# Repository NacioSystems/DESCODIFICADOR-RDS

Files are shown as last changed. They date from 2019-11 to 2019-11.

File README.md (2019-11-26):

# DESCODIFICADOR RDS

## de NacioSystems:

Versión 1.0
Fecha: enero 2018

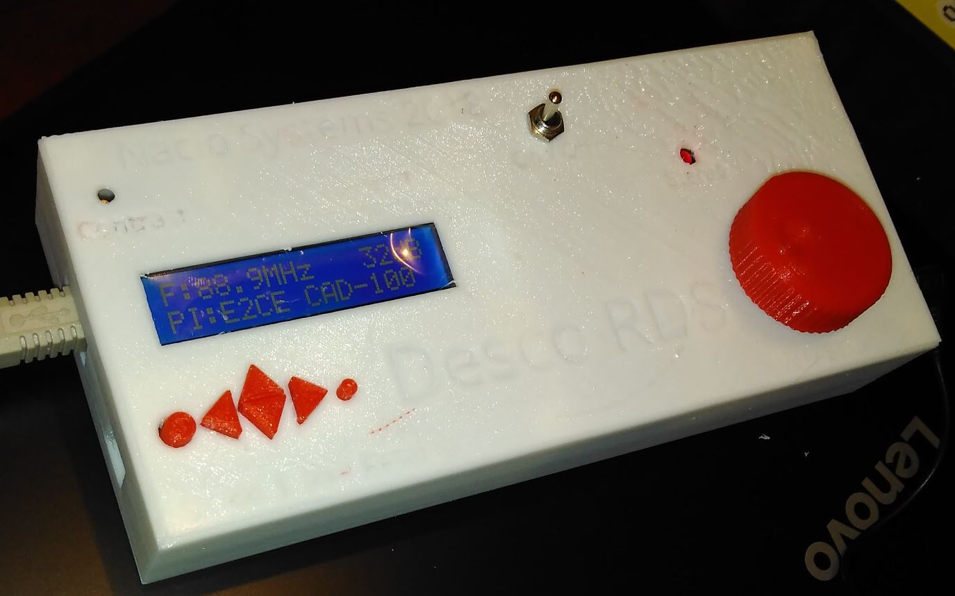
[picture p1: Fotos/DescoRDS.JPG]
DESCO RDS Desco RDS


### Indroducción:

Se trata de una radio FM con funciones básicas RDS. A través de un Arduino UNO se controla el receptor de FM con RDS Si-4703. El conjunto se complementa con una bononera y display de la placa LCD KeyPad, además de un encoder rotativo. El Arduino UNO funciona con lógica a 5V, mientras que el Si-4703 funciona a 3.3V, por ello incluye una placa adaptadora de niveles. Todo está montado sobre una caja impresa en 3D, incluyendo cuatro pilas AA de 1,5V. Es necesario disponer de unos auriculares con jack de 3,5, para las funciones de antena y poder escuchar los contenidos estereofónicos.

Tambien funciona sin baterías, conectando el puerto USB a una fuente de alimentación.

A través de la botonera se pude pasar de una frecuencia a otra, mediante escaneo a la siguiente frecuencia que se puede recibir con un nivel mínimo o por pasos de 100KHz. En el display nos indicará la frecuelncia de recepción y en caso de disponer de servicios RDS veremos también el código hexadecimal PI de la emisora y su nombre PS. También se indica el nivel de recepción de la señal radio en bornas del conector de antena/auriculares, en dBuV. Dependiendo del modo, el encoder rotativo servirá par subir bajar el volumen, que es la función principal, pero puede funcionar para subir y bajar frecuencias. Cuando una emisora está bien sintonizada se activará el LED indicando la recepcón estereofónica. Las pulsaciones de la botonera y el encoder generan un pequeño bip en el buzzer, confirmando que la tecla se ha pulsado correctamente.

No sólo es una radio convencional, es un descodificador de señal RDS, aportando la información en diferentes pantallas y modos, seleccionables con los bonones "up" y "down". Entre otras cosas aporta la siguiente información, tanto por el dsplay LCD como a través del puerto serie. En el caso de utilizar el puerto serie, al tener menos limitaciones, se ofrece una información más compelta:

* PI código hexadecimal de identificación de programa
* PS nombre de la emisora de radio o programa musical
* TP si el programa da información de tráfico
* TA si se están dando contenidos de anuncio de tráfico
* M/S si es música o palabra lo emitido
* PTY la identificación de tipo de programa, noticias, música,...
* RTX el radiotexto que pueda estar emitiendo la emisora A/B
* N, número de frecuencias alternativas
* AF frecuencias alternativas de la emisión y nivel de recepción de cada frecuencia
* G A/B informacíon estadística sobre los paquetes y grupos emitidos en RDS
* Hora UTC, Información de la fecha y hora transmitida, en caso de emitirla.

Otra funcionalidad que contempla es la grabación en la memoria EEPROM del Arduino UNO de 10 memorias con las emisoras favoritas, memoria no volátil que se mantiene incluso si se queda sin alimentación. Por defecto incluye 10 memorias ya cargadas de frecuencias del entorno de Santiago de Compostela, pero a través del teclado permite guardar en cada posición de memoria datos de nuevas emisoras.

### Materiales electrónicos:

* [Arduino UNO R3][2]
* [LCD Keypad for Arduino UNO][3]
* [Receptor FM SI-4703][4]
* [Adaptador de niveles lógicos 3,3V a 5V][5]
* [Encoder rotativo eje largo][11]
* [Porta pilas 4xAA][6]
* [Buzzer][7]
* Otro pequeño material como diodo LED, interruptor endendido, cables...

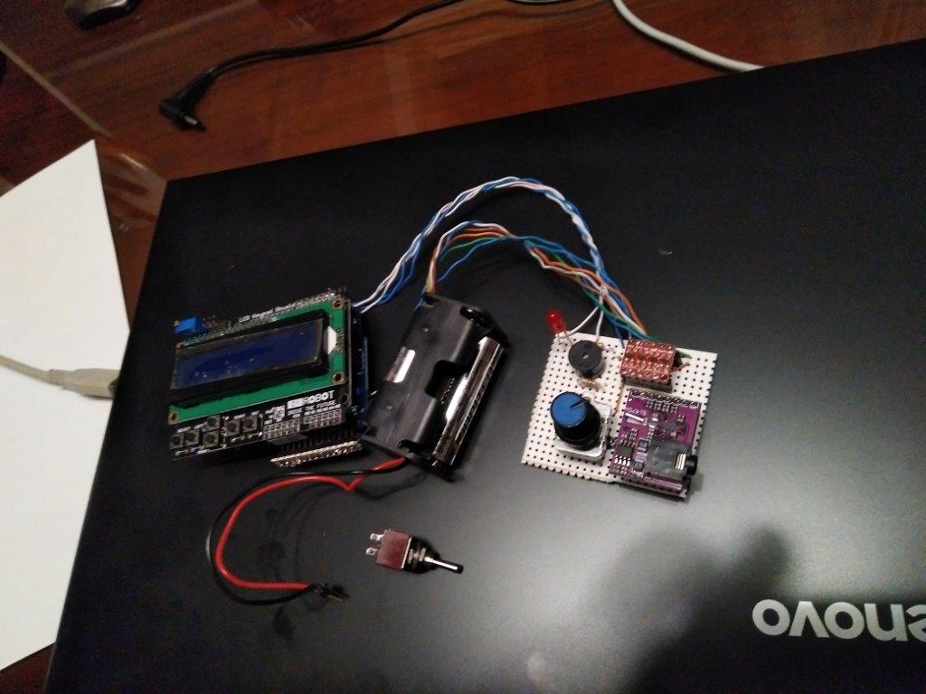
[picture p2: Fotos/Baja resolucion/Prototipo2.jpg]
Prototipado


### Piezas impresas:

La caja soporte está realizada a través de impresión en 3D, con PLA. Los modelos STL se pueden descargar del repositorio:

* [Caja principal][8]
* [Botonera][9]
* [Tapa posterior][10]

[8]: https://github.com/NacioSystems/DESCODIFICADOR-RDS/blob/master/Modelos%203D/DescoRDS.stl
[9]: https://github.com/NacioSystems/DESCODIFICADOR-RDS/blob/master/Modelos%203D/botones.stl
[10]: https://github.com/NacioSystems/DESCODIFICADOR-RDS/blob/master/Modelos%203D/tapa.stl

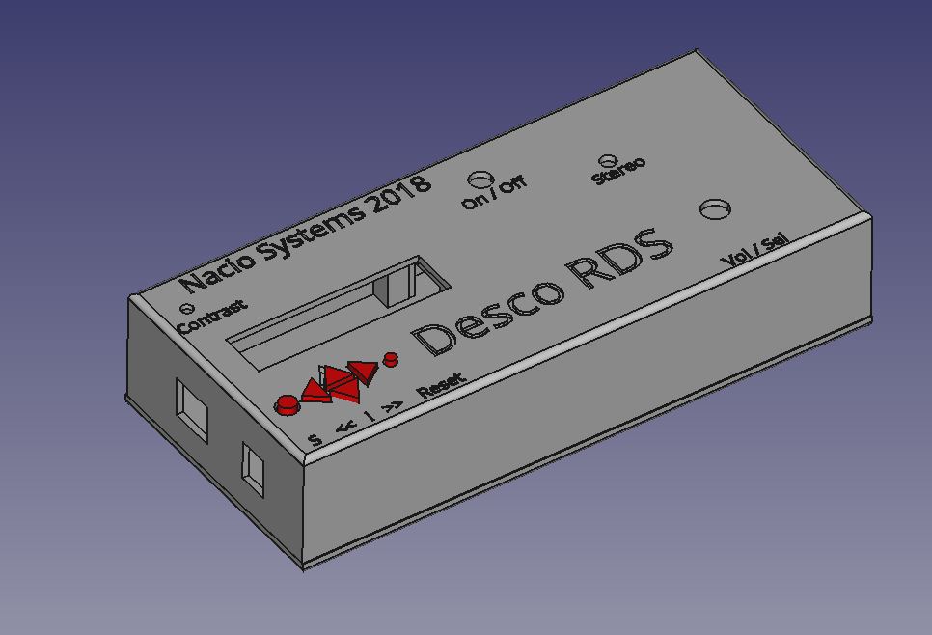
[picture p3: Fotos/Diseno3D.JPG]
Caja 3D Diseño caja 3D


### Mejoras pendientes:

Está pendiente incluir una antena telescópica fija, para no depender de los auriculares. También un pequeño amplificador con altavoz para escuchar la señal emitida sin auriculares. Implementar el cambio automático de emisora a través de las frecuencias alternativas y el código PI, cuando la calidad de recepción se reduce.

Otra funcionalidad es la cambiar el Arduino UNO por un NodeMCU ESP8266. De esta manera nos ahorramos la placa adaptadora de niveles al funcionar todo a 3,3V y  podremos hacer una gestión y control remoto de todo el dispositivo a través de TCP/IP por Wifi.

### Autor:

**Ignacio Otero**

### Agradecimientos:

Muchas gracias [**J_RPM**][1] por tus tutoriales sobre RDS.

Gracias también a [**Spark Fun Electronics**][4], de quien aprovecho las librerías Si4703.

### Licencia:

Todos estos productos están liberados mediante Creative Commons Attribution-ShareAlike 4.0 International License.

[1]: http://j-rpm.com/category/fundamentos-de-la-transmision-fm/page/3/
[2]: https://store.arduino.cc/arduino-uno-rev3
[3]: https://www.amazon.es/Aptotec-Keypad-Arduino-Mega2560-Duemilanove/dp/B01BI6UKHW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
[4]: https://learn.sparkfun.com/tutorials/si4703-fm-radio-receiver-hookup-guide/all
[5]: https://tienda.bricogeek.com/herramientas-de-prototipado/82-conversor-de-niveles-logicos-33-5v.html
[6]: https://tienda.bricogeek.com/componentes/943-base-para-baterias-4xaa-cilindrica.html
[7]: https://tienda.bricogeek.com/componentes/299-zumbador-piezo-12mm.html
[11]: https://www.amazon.es/Ociodual-CODIFICADOR-ROTATORIO-PULSADOR-Encoder/dp/B075NJSMWM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

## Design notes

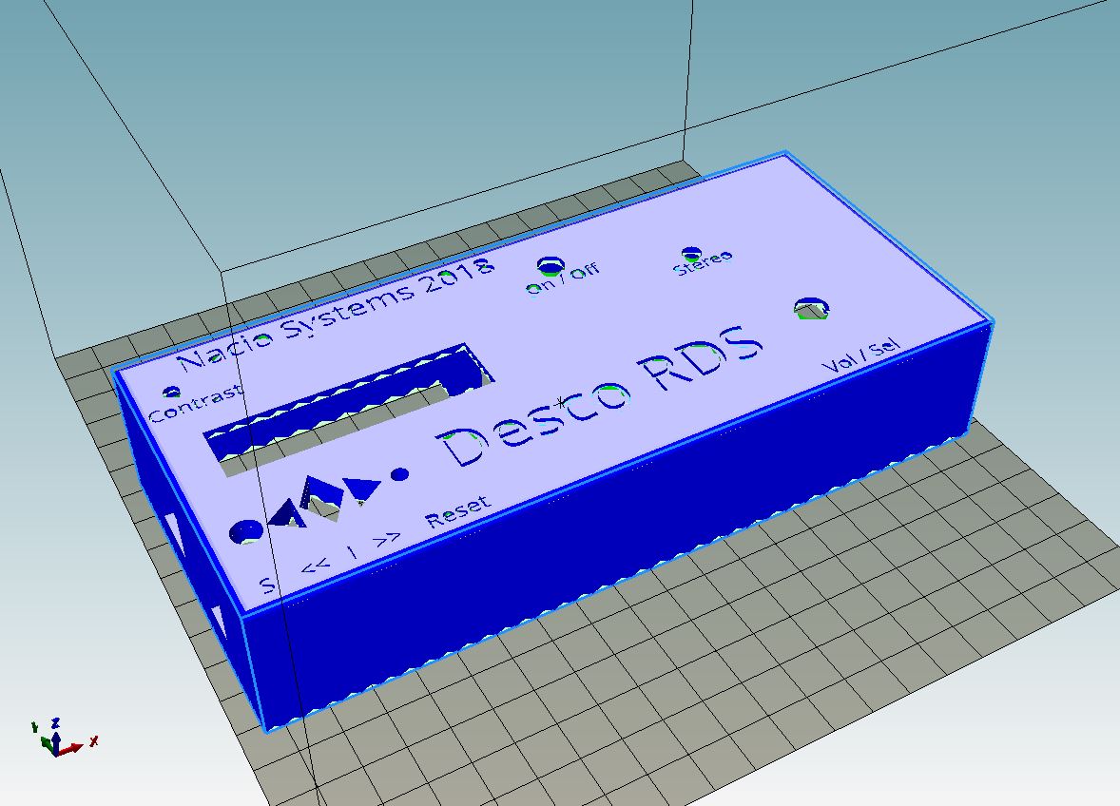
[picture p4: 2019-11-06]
Fotos/Caja3D.JPG

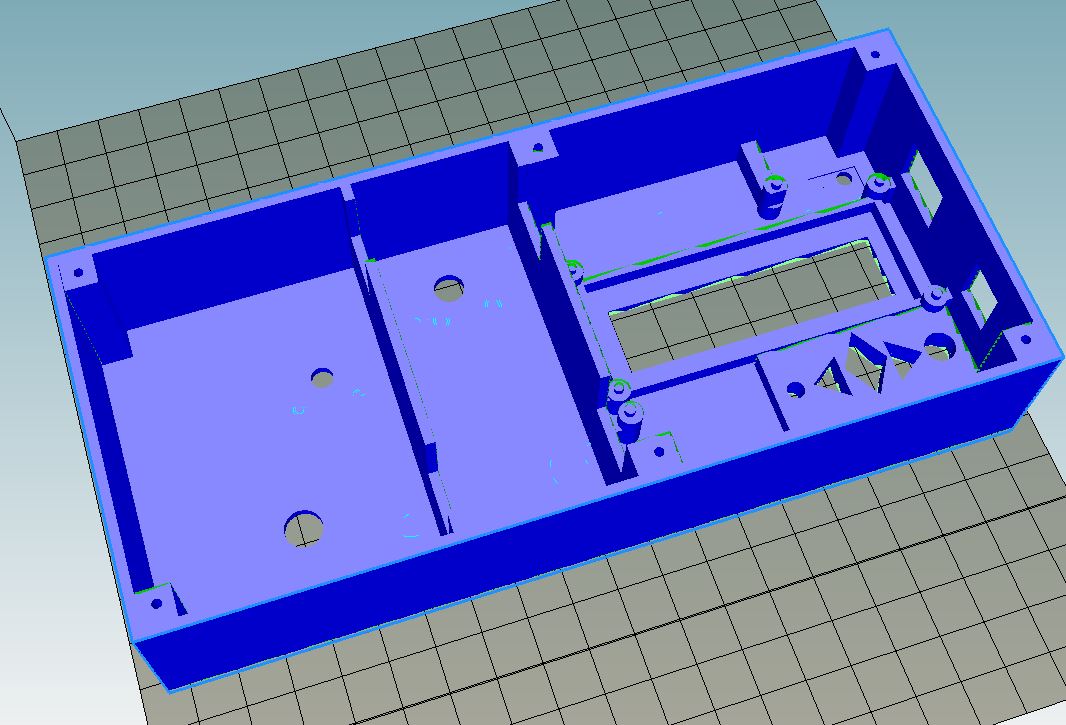
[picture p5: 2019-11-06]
Fotos/Interior.JPG

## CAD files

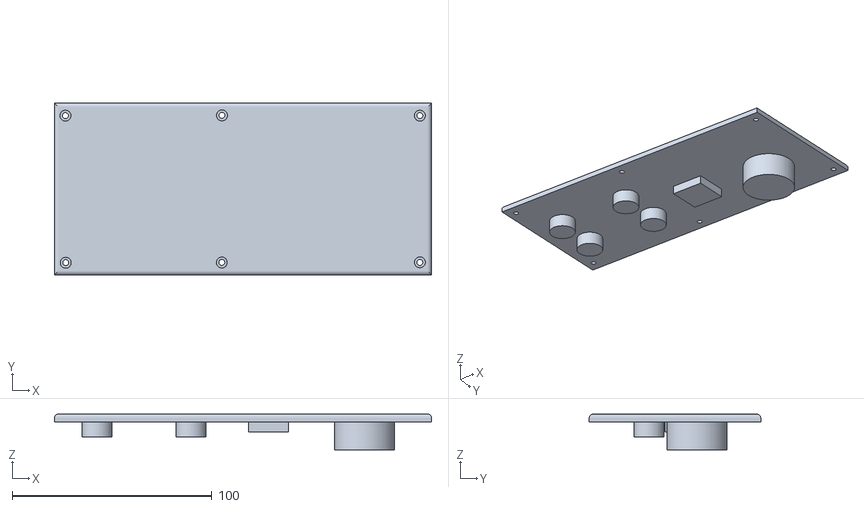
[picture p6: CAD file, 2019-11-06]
Modelos 3D/Tapa.stl
188.9 x 86.0 x 18.0

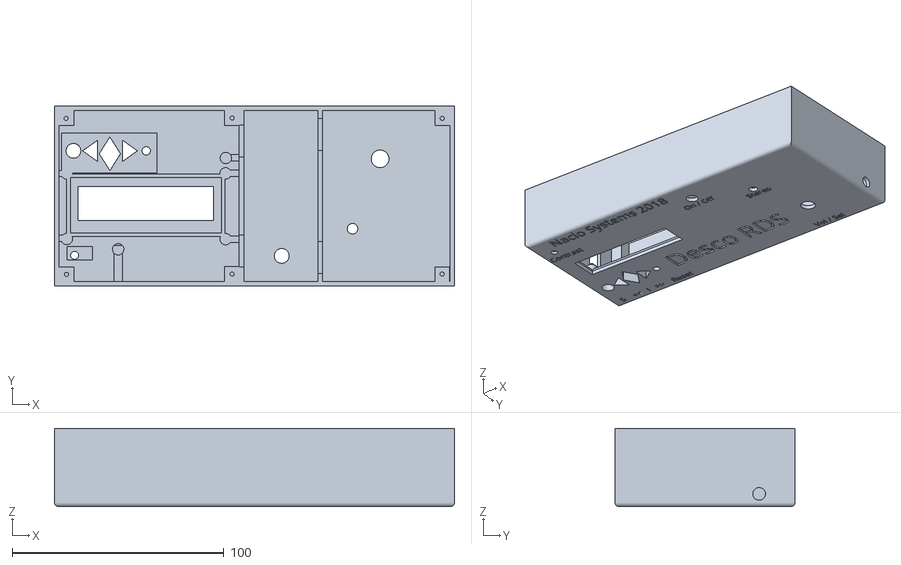
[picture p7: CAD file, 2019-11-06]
Modelos 3D/DescoRDS.stl
188.9 x 85.0 x 37.0

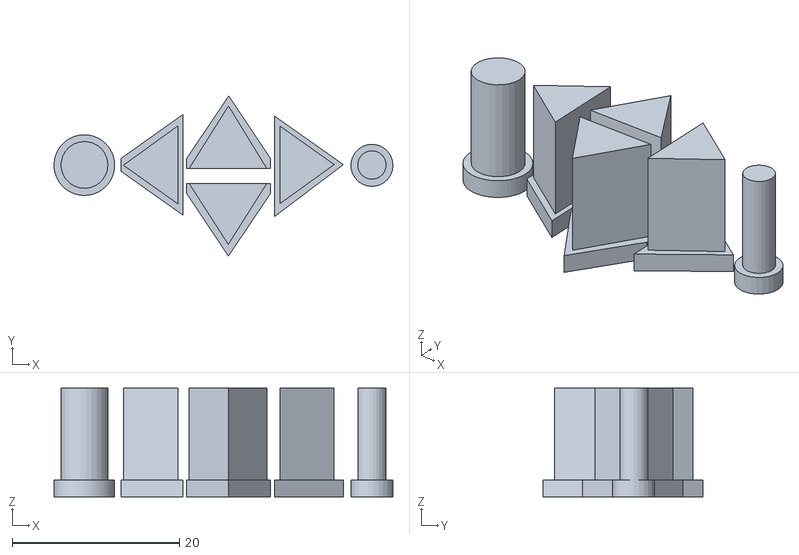
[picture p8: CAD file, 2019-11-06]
Modelos 3D/botones.stl
40.5 x 19.1 x 13.0

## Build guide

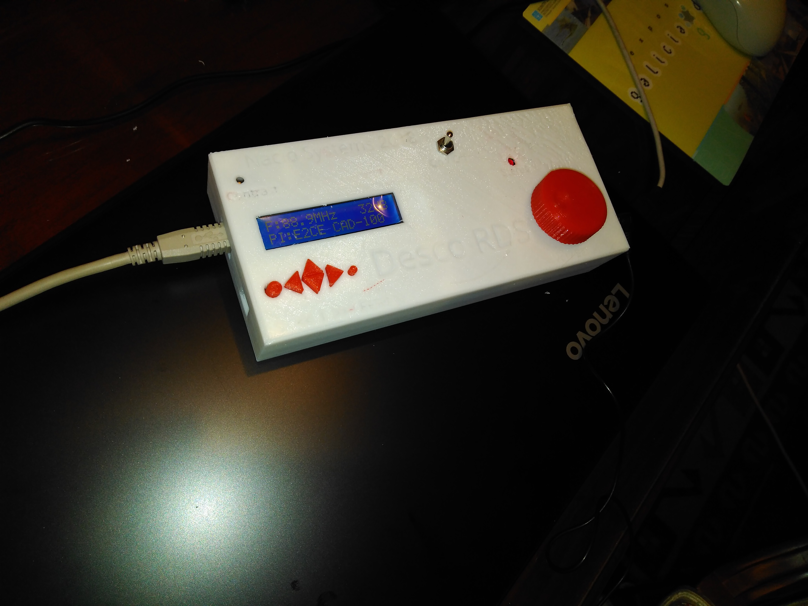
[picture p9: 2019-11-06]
Fotos/Montaje.jpg

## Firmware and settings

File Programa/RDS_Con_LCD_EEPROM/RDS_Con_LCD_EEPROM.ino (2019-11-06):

/*
  Modificado por Ignacio Otero para obtener datos de RDS en enero 2018
  Referencias:
  - Spark Fun
  1-6-2011
  Spark Fun Electronics 2011
  Nathan Seidle

  - CENELEC 50067 / 1998

  - J_RPM WWW.YOUTUBE.COM/
  https://www.youtube.com/watch?v=Hiti3FGuOgI&list=PLu7bTAqPV8_y0-5Ok_vPMW8Hp26_XmIxC

  This code is public domain but you buy me a beer if you use this and we meet someday (Beerware license).

  To use this code, connect the following 5 wires:
  Arduino : Si470x board
  3.3V : VCC
  GND : GND
  A5 : SCLK
  A4 : SDIO
  A3 : RST
  D3  SDIO2 (Int 1)

  Look for serial output at 57600bps.

  The Si4703 ACKs the first byte, and NACKs the 2nd byte of a read.

  1/18 - after much hacking, I suggest NEVER write to a register without first reading the contents of a chip.
  ie, don't updateRegisters without first readRegisters.

  If anyone manages to get this datasheet downloaded
  http://wenku.baidu.com/view/d6f0e6ee5ef7ba0d4a733b61.html
  Please let us know. It seem to be the latest version of the programming guide. It had a change on page 12 (write 0x8100 to 0x07)
  that allowed me to get the chip working..


 Si4703 CUIDADO! ESTE CHIP SÓLO ADMITE NIVELES DE 3,3V
--------------------------------------------------------------------

En los puertos están disponibles, A1, A2 y D0, D1 (RX / TX)
*/

#include "Configuracion.h" // Están todas las definiciones del programa
#include <Wire.h>
#include <EEPROM.h>       // Guardamos los datos de las memorias en la EEPROM

// Definimos un objeto RADIO de la clase Si4703 con las siguentes conexiones
// Si4703(int resetPin, int sdioPin, int sclkPin, int intPin);
#include "Si4703.h"
Si4703 RADIO(resetPin, SDIO, SCLK, GPIO2);

// Definimos un objeto lcd de la clse LiquidCrystal   
#include <LiquidCrystal.h>
LiquidCrystal lcd(RS, ENABLE, DB4, DB5, DB6, DB7);


// VARIABLES GENERALES
             int ModoPantalla = 1;  // Empieza el LCD con la pantalla principal
             boolean ModoConfiguracion = false;


             int Tecla = btnNONE; // Por defecto la tecla leida será 5

             char printBuffer[50]; // Utilizamos este string para formateo de impresión
             uint16_t si4703_registers[16]; //Son los 16 registros de Si4703, cada uno de 16 bist


             // Variables RDS en Grupo 0A
             uint16_t Pi = 0x00; // PI Program Station Identification Ah + Al
             uint8_t GP = 0; // Program Group Bh, b5-b8
             char Bcero = 'A'; // Es el tipo de grupo A=0 o B=1 en Bh bit 4
             boolean TP = 0, TA = 0; // Traffic Program b3 Bh y Traffic Anouncement b5 Bl
             uint8_t PTY = 0; // Program Type Bh + Bl b6-b8, 5 bits
             //String TextoPTY = "Indefinido"; // Esto lo hago para poner el texto de programa
             boolean MS = 0; // Modo de programa 0 Speech 1 Music
             String MSTexto = "_____"; // En vez de poner el bit pongo Speech o Music
             boolean DI = 0, PTYdinamico = 0, Comprimido = 0, Artificial = 0, Estereo = 0;
             uint8_t Control = 0; // 2 bits C1 y C0 para decodificar PS
             char PS[9] = "________\0"; // Program Station Name Ch + Cl en Grupo 0A
             uint8_t AF[26]; // Tabla de frecuencias alternativas en Grupo 0A
             uint8_t NAF = 0; // Número de AF en Grupo 0A
             int ContadorAF = 0; // Vamos contando AF hasta el máximo de 26 o código 0xCD

             // Variables del Grupo 2A 2B radio texto
             String RTA = "_______________________________________________________________"; // Radio texto en grupo A, 4 bytes en C y D
             String RTB = "_______________________________________________________________"; //Radio texto en grupo B, 2 bytes en D
             boolean TextAB = 0; // bit 5 de Bl para G2, para leer RT A o B
             boolean BanderaAB = 0; // Para comprobar que TextAB cambia

             // Varialbes del grupo 4A horas y minutos
             uint8_t Horas=0;
             uint8_t Minutos=0;
             uint8_t Segundos=0;
             int UTC=0;            // UTC puede ser negativo
             unsigned long MJD=0;  // MJD ocupa 17 bits, hacen falta 4 bytes
             uint8_t Dia=0;
             uint8_t Mes=0;
             uint16_t Ano=0;       // Es más de 256
             uint8_t ContDia=0;
             
             const char* TextoPTY[32] = {"None",    // 0
                                         "News",    // 1
                                         "Affairs", // 2
                                         "Info",    // 3
                                         "Sport",   // 4
                                         "Educate", // 5
                                         "Drama",   // 6
                                         "Culture", // 7
                                         "Science", // 8
                                         "Varied",  // 9
                                         "Pop M",   //10
                                         "Rock M",  //11
                                         "Easy M",  //12
                                         "Light M", //13
                                         "Classics",//14
                                         "Other M", //15
                                         "Weather", //16
                                         "Finance", //17
                                         "Children",//18
                                         "Social",  //19
                                         "Religion",//20
                                         "Phone In",//21
                                         "Travel",  //22
                                         "Leisure", //23
                                         "Jazz",    //24
                                         "Country", //25
                                         "Nation M",//26
                                         "Oldies",  //27
                                         "Folk M",  //28
                                         "Document",//29
                                         "TEST",    //30
                                         "Alamr!"   //31
                                         };
                                          
             const char* DiaSem[7]={"lunes","martes","miercoles","jueves","viernes","sabado","domingo"}; // Para que funcione tiene que ser puntero de Char

             // Grupos
             uint16_t GrupoA[16]; // Es para contar los grupos recibidos
             uint16_t GrupoB[16]; 
             uint16_t ContadorGrupo = 0; // Cuenta el total de grupos recibidos

             // Valores leidos de Si4703 en variables
             byte rssi = 0; // Nivel recibido en registro STATUSRSSI[0:7]
             // Son incrementos de 1dBuV, máximo 75 dBuV

             // Control del volumen extendido
             boolean VolumenExtendido = 0; // Por defecto=0;
             uint8_t Volumen = 10; // El máximo sería 31, 5 bits
             boolean Mute=true;
             // Si es menor que 17 sería Extendido
             uint8_t VolumenAnterior=Volumen;

             // Brillo pantalla lcd
             uint8_t Brillo=50;
             
             // Variables utilizadas en las interrupciones 
             volatile int Contador = 875; // La utilizaremos para la sintonia 875 - 1080
                                          // el volumen 0 - 31
                                          // Brillo del display 0 - 255
             volatile boolean RDSOK = false; // Nos dirá por interrupción si hay datos RDS
             boolean ESTEREOK = true; // El Si4703 nos da información de si la señal es estero                             

             // Memorias prefijadas 
             struct ObjetoMemoria {                      // Cada memoria ocuparía 9 + 2 + 2 = 13 bytes
                                    char     PS[9];      // Es el nombre de la emisora memorizada, poner null en el 9
                                    uint16_t Frecuencia; // Es la frecuencia en cientos de KHz, ejem. 875 es 87.5
                                    uint16_t Pi;         // Es la Identificación de Programa en hexadecimal
                                    };
             
             ObjetoMemoria Memorias;                     // En un array de 10 memorias metemos los datos de las memorias
                                                         // Ocuparían 13 x 10 = 130 bytes
                                                         // Los parámetros se llamarían por Memorias[i].Frecuencia...
                                                         
             int8_t ContadorMemorias = 5; // Cadena 100
             unsigned long tiempo = 0;
             unsigned long TSeg=0;
             boolean BuzzerON=true;

 
void setup() {
  // Inicializamos Interrupciones y Encoders
  pinMode(encoderA, INPUT_PULLUP); // Van conectados directamente
  pinMode(encoderB, INPUT_PULLUP); // a 5V, por eso pullup
  pinMode(GPIO2, INPUT_PULLUP);    // Aunque en la configuraión de GPIO ya esta a pull_up
  pinMode(resetPin, OUTPUT);       // Utilizamos A4 como digital esto ya lo hace init()
  pinMode(BuzzerPin, OUTPUT);      // La salida de D11 será la señal buzzer
  attachInterrupt(0, LeerEncoder, CHANGE); // Interrupción 0 para encoder
  attachInterrupt(1, DatosRDS, FALLING);   // Interrupcion 1 para RDS 
   
  
  // Inicializar el LCD
  lcd.begin(16, 2);
  lcd.setCursor(0, 0);
  lcd.print("Ignacio Otero");
  lcd.setCursor(0, 1);
  lcd.print("Desco RDS 2018");
  delay(2000);
  lcd.noDisplay();
  delay(2000);
  lcd.display();

  pinMode(STATUS_LED, OUTPUT);
  pinMode(BOTONES, INPUT); // Leemos el teclado por A0
  pinMode(A1, INPUT); // Optional trimpot for analog station control
  pinMode(BLACK_TILT_CONTROL, OUTPUT);
  
  Serial.begin(57600);
  Serial.println();
  Serial.println(F("Ignacio Otero"));
  Serial.println(F("Desco RDS 2018"));
  for(int i=255; i>=0; i--) {
    analogWrite(BLACK_TILT_CONTROL, i);
    delay(10);
    }
   
/*
//**********************************************************************
// Todo esto lo enmarcaremos para comentar
// Volcamos datos en La EEPROM la primera vez
// Después sólo guardamos datos cuando se cambia una memoria
// Primero cargamos la informacion en la variable Memorias
//                            PS         Frec.       Pi
            Memorias[0] = {{'R','N','E',' ','1'},             1031,    0xE211}; // 1 RNE1
            Memorias[1] = {{'R','N','E',' ','2'},              981,    0xE212}; // 2 RNE2
            Memorias[2] = {{'R','N','E',' ','3'},              990,    0xE213}; // 3 RNE3
            Memorias[3] = {{'R','.','G','A','L','E','G','A'},  962,    0xE4E0}; // 4 RG
            Memorias[4] = {{'C','A','D','-','1','0','0'},      889,    0xE2CE}; // 5 C100
            Memorias[5] = {{'R','G','M','U','S','I','C','A'}, 1042,    0xE4E1}; // 6 RG MUSICA
            Memorias[6] = {{'L','O','S',' ','4','0'},          906,    0xEB19}; // 7 LOS 40
            Memorias[7] = {{'R','A','D','I','O','V','O','Z'}, 1061,    0xE2A2}; // 8 Radio Voz
            Memorias[8] = {{'K','I','S','S',' ','F','M'},      894,    0xE2EC}; // 9 KISS
            Memorias[9] = {{'C','O','P','E'},                 1021,    0xEBAB}; // 10 COPE
// Terminamos todos los PS con el carácter null
for(int i=0; i<10; i++) Memorias[i].PS[8]='\0';

// Despues pasamos estos datos a la EEPROM, sólo la primera vez
int EPA = 0; // EPA EEPROM ADDRESS = 0;
for(int i=0; i<10; i++) {
  EEPROM.put(EPA, Memorias[i]); // Leemos cada Memoria de su valor en EEMPROM
  EPA += sizeof(ObjetoMemoria); // Saltamos 12 bytes de cada vez
  }
                                     
//***********************************************************************
*/

// Cargamos las memorias de la EEPROM
// En cada reinicio
int EPA = 0; // EEPROM address
Serial.println(F("\n\nLeemos los valores de las memorias de la EEPROM"));
Serial.println(F("M      PS   \tFREC\tPI"));
for(int i=0; i<10; i++) {
  EEPROM.get(EPA, Memorias); // Leemos cada Memoria de su valor en EEMPROM
  EPA += sizeof(ObjetoMemoria); // Saltamos 12 bytes de cada vez
  sprintf(printBuffer, "%02d- %08s\t%04d\t%04X ",i+1, Memorias.PS, Memorias.Frecuencia, Memorias.Pi); //currentChannel / 10, currentChannel % 10);
  Serial.println(printBuffer);
  }
      
  RADIO.Init(); // Inicializaición Si4703 y protocolo 2 hilos Wire

  // Aviso musical, Do Re Mi
  tone(BuzzerPin,261,100);
  delay(100);
  tone(BuzzerPin,294,100);
  delay(100);
  tone(BuzzerPin,329,100);
  
  for(int i=0;i<Brillo;i++) {
    analogWrite(BLACK_TILT_CONTROL, i);
    digitalWrite(STATUS_LED, HIGH);
    delay(50);
    digitalWrite(STATUS_LED, LOW);
    i+=4;
    }

  TSeg=millis();

}

void loop() {
  char option;
  char vol = 10;
  Contador=vol;
  char VCH=' ';
  uint16_t currentChannel = 889; //Default the unit to a known good local radio station
  tiempo = millis();
 /* // borrar Scanner por plotter serie
   while (1) {
           for(int i=875;i<1080;i++) {
             if (Serial.available())
                   if (Serial.read() == 'x') break;
             RADIO.gotoChannel(i);
             si4703_readChannel();
             rssi = RADIO.Registers[STATUSRSSI] & 0x00FF; //Mask in RSSI
             Serial.println(rssi, DEC);
             delay(100);
             }
             delay(5000);
           }  

*/ // borrar

  RADIO.gotoChannel(currentChannel);

  // Leemos los datos de RDS antes de presentar en pantalla
  
  while (1) {
    if(RDSOK) LecturaRDS();  // Cada vez que pulsamos una tecla leemos los datos de RDS antes de 
    DatosBasicos(); // Poner datos en pantalla.

    Serial.println(F("Teclea opcion ?"));

    while (!Serial.available()) // Está en este blucle salvo que por Serial pasemos una tecla
    {
      if(RDSOK) LecturaRDS();// Solo leemos los datos si se hay interrupción
      Tecla=LeerBotonera();  // el encoder controla el volumen
      if(Contador>32) Contador=32;
      if(Contador<0) Contador=0;
      if(Contador!=vol) {     // Si movoemos el encoder
           ModoPantalla=14;   // Activamos la pantalla de volumen
           DysplayLCD();
           vol=Contador;
           ModoPantalla=1;    // Volvemos a la pantalla principal
          }
      if(Tecla!=btnNONE)
        {
           
           switch(Tecla)
           {
              case btnDOWN:  // Cambiamos display a siguiente
                 ModoPantalla++;
                 lcd.clear();
                 if((ModoPantalla>8)&&(ModoConfiguracion==0)) ModoPantalla=1;
                 else if((ModoPantalla>13)&&(ModoConfiguracion==1)) ModoPantalla=9;
                 break;

              case btnUP:   // Cambiamos display a anterior
                 ModoPantalla--;
                 lcd.clear();
                 if(ModoPantalla<1&&(ModoConfiguracion==0)) ModoPantalla=8;
                 else if((ModoPantalla<1)&&(ModoConfiguracion==1)) ModoPantalla=13;
                 break;

              case btnLEFT: // Escaneamos hacia abajo
                   if(ModoPantalla==2) {
                          Sintonia(-1);
                          break;
                   }
                   else if(ModoPantalla==5)
                      {
                        for(int i=0;i<16;i++) {
                           lcd.scrollDisplayRight();
                           delay(200);
                            }
                        break;
                      }
                   LimpiaRDS();
                   RADIO.seek(SEEK_DOWN);
                   break;
              

              case btnRIGHT: // Escaneamos hacia arriba
                   if(ModoPantalla==2) {
                          Sintonia(1);
                          break;
                       }
                   else if(ModoPantalla==5)
                      {
                        for(int i=0;i<16;i++) {
                            lcd.scrollDisplayLeft();
                            delay(200);
                            }
                        break;
                      }
                   LimpiaRDS();
                   RADIO.seek(SEEK_UP);
                   break;
                   
              case btnSELECT: // Modo configuracion
                   ModoPantalla=9;
                   ModoConfiguracion=!ModoConfiguracion;
                   break;


              default:
                  break; // Nada
           }
        delay(500); // Cuando terminamod de pulsar una tecla espera 500ms  
        }
      

      // Cada segundo actualizamos el tiempo
      // Aprovechamos para leer los datos de Si4703
      // ajustamos canal
      // ajustamos bit de estereo  
      if((millis()-TSeg)>1000)
        {
          // Leemos la frecuencia sintonizada
          currentChannel=RADIO.readChannel(); // Leemos el valor sintonizado

          // Activamos desactivamos el Led de estereo
          digitalWrite(STATUS_LED, ESTEREOK=RADIO.Registers[STATUSRSSI] & (1 << ST)); 

          // Actualizamos pantalla lcd
          DysplayLCD();
          tiempo=millis();

          // Actualizamos hora
          Segundos++;
          if(Segundos>59) {
              Segundos=0;
              Minutos++;
              if (Minutos>59){ 
                Minutos=0;
                Horas++;
                if(Horas>23) Horas=0;
              }
              
          }
          TSeg=millis();
        }
    }

    option = Serial.read();

    if (option == '0')  {
      String Opcion[4] = "";
      int i = 0;
      int mil=1000;
      uint16_t canal=0;
      LimpiaRDS();
      Serial.println(F("Teclea frecuencia sin puntos cuatro cifras: Ejem 0875"));
      while (1) {
        while (!Serial.available()) {
          //Nada;
          }
        option = Serial.read();
        if (option == char(13)) break;
        canal+=(option-48)*mil;
        mil/=10;
        Opcion[i] = option;
        i++;
        if (i > 3) break;
        }
        if(i==2) canal/=10;
      Serial.print(F("Cambiado a canal: "));
      Serial.println(canal);
      LimpiaRDS();
      RADIO.gotoChannel(canal);
      Serial.println(F(" "));
      if(canal>1080) canal = 1080;
      if(canal<870) canal = 870;
      Serial.println(canal);
    }
    else if (option == '1')  {
      LimpiaRDS();
      Serial.print(F("\nMemoria: "));
      Serial.println(ContadorMemorias + 1);
      int EPA = ContadorMemorias * sizeof(ObjetoMemoria); // Saltamos 12 bytes de cada vez
      EEPROM.get(EPA, Memorias); // Leemos cada Memoria de su valor en EEMPROM
      currentChannel = Memorias.Frecuencia;
      ContadorMemorias++;
      if (ContadorMemorias > 9) ContadorMemorias = 0;
      RADIO.gotoChannel(currentChannel);
    }
    else if (option == '2') {
      Serial.println(F("Mute toggle"));
      Mute=!Mute;
      RADIO.setVolume(vol,Mute); // Cuando es false no afecta el volumen
      }
    else if (option == '3') {
      Serial.println(F("\n\nContenido memorias:"));
      // Leemos las memorias de la EEPROM
      int EPA = 0; // EEPROM address
      Serial.println(F("Leemos los valores de las memorias de la EEPROM"));
      Serial.println(F("M      PS   \tFREC\tPI"));
      for(int i=0; i<10; i++) {
        EEPROM.get(EPA, Memorias); // Leemos cada Memoria de su valor en EEMPROM
        EPA += sizeof(ObjetoMemoria); // Saltamos 12 bytes de cada vez
        sprintf(printBuffer, "%02d- %08s\t%04d\t%04X ",i+1, Memorias.PS, Memorias.Frecuencia, Memorias.Pi); //currentChannel / 10, currentChannel % 10);
        Serial.println(printBuffer);
        }
        Serial.print(F("Memoria actual seleccionada: "));
        Serial.println(ContadorMemorias);
    }
    else if (option == '4') {
      LimpiaRDS();
      RADIO.seek(SEEK_UP);
    }
    else if (option == '5') {
      LimpiaRDS();
      RADIO.seek(SEEK_DOWN);
    }
    else if (option == '6') {
      Serial.println(F("\n\n\n\n********************************************************************************************"));
      Serial.println(F("DESCARGA INFORMACIÓN RDS:"));
      DatosBasicos();
      PantallaSerial();

    }
    else if (option == 'v') {
      Serial.println();
      Serial.print(F("Volumen:"));
      Serial.print(Volumen);
      Serial.print(F(" EXT="));
      Serial.println(VolumenExtendido, BIN);
      Serial.println(F("+) Up"));
      Serial.println(F("-) Down"));
      Serial.println(F("x) Exit"));
      while (1) {
        if (Serial.available()) {
          option = Serial.read();
          if ((option == '+')||(option=='-')) {
            Volumen=ActuacionVolumen(option, btnNONE);
            Serial.print(F("Volumen: "));
            Serial.print(Volumen);
            Serial.println(F(" "));
          }
          else if (option == 'x') break;
        }
      }
    }
    else if (option == 'w') {
      LimpiaRDS();
      Sintonia(1);
     }
    else if (option == 's') {
      LimpiaRDS();
      Sintonia(-1);
    }
    else if(option == '?') {      
      Serial.println(F("Configurado para Europa"));
      Serial.println(F("0) Introducir canal"));
      Serial.println(F("1) Siguiente Memoria"));
      Serial.println(F("2) Mute On/Off"));
      Serial.println(F("3) Lectura memorias"));
      Serial.println(F("4) Seek up"));
      Serial.println(F("5) Seek down"));
      Serial.println(F("6) Descarga datos RDS"));
      Serial.println(F("v) Volumen"));
      Serial.println(F("w) Sintonia up"));
      Serial.println(F("s) Sintonia down"));
      Serial.println(F("?) Esta pantalla"));
      Serial.print(F(": "));
    }
    else {
      Serial.print(F("Eleccion = "));
      Serial.println(option);
    }
  }
}
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

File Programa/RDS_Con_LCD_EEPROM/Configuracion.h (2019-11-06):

/* Este archivo de configuarción es para el programa Desco RDS

PINES UTILIZADOS POR ARDUINO UNO

  LCD 16x2 Utiliza los pines
---------------------------------  
D4  DB4
D5  DB5
D6  DB6
D7  DB7
D8  RS
D9  ENABLE
D10 BLACK TILT CONTROL
A0  BOTONES (Lecturas: Select = 720, Izq = 479, Arrb. = 131, Abaj.306, Der = 0;

  ENCODER ROTATIVO
----------------------------------
D2   encoderA (Int 0)
D12  encoderB

  Si4703 RDS DECODER
----------------------------------
D3  GPIO2 (Int 1)
A3  RESET PIN
A4  SDIO
A5  SCLK

  LED rojo
----------------------------------
D13 STATUS_LED


   BUZZER
---------------------------------- 
D11 BuzzerPin

En los puertos están disponibles, A1, A2 y D0, D1 (RX / TX)

*/
//Conexiones con Si4703 y Arduino
      #define GPIO2 3  // D3 Interrupcion 1 para deco RDS
      #define STATUS_LED 13
      #define resetPin A3
      #define SDIO A4 //SDA/A4 en Arduino 20 en Mega
      #define SCLK A5 //SCL/A5 en Arduino 21 en Mega

// Pines utilizados por LCD
      #define DB4 4
      #define DB5 5
      #define DB6 6
      #define DB7 7
      #define RS 8
      #define ENABLE 9
      #define BLACK_TILT_CONTROL 10
      #define BOTONES A0

// Valores para leer los botones y panel LCD
      #define btnRIGHT  0
      #define btnUP     1
      #define btnDOWN   2
      #define btnLEFT   3
      #define btnSELECT 4
      #define btnNONE   5

// Valores utilizados por el Encoder Rotativo
// Estos dos pines son interrupciones 0 y 1
      #define encoderA 2
      #define encoderB 12
// Tiempo para eliminar los rebotes en Encoder
      #define IntevaloEncoder 100

// Datos del buzzer
      #define BuzzerPin 11
      #define NotaTeclado 55
      #define NotaEncoder 84
      #define TiempoNota 25
